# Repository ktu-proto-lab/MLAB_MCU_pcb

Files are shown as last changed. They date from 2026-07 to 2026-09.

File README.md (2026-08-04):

# MLAB_MCU Test PCB

Test board for the taped-out `MLAB_MCU` (top level: `ibex_simple_system`), packaged in a
QFN32 / MLP5X5-32 open-cavity package.

Socket: https://lt.farnell.com/3m/232-5205-01/test-socket-qfn-32pos-0-5mm-th/dp/2668401?cfm=true

Two board versions, one schematic project:

| Version | Purpose | Notes |
|---|---|---|
| **A - Socketed (Priority)** | Screening / characterisation of multiple dies | Full instrumentation.  |
| **B - Direct solder (Future)** | Demo, long-term lab setup | Same schematic, instrumentation depopulated (fixed LDOs, fixed oscillator). |

---

## 1. Chip summary

- Ibex RV32IMC core, Wishbone shared interconnect
- IMEM 8 kB, DMEM 4 kB
- Peripherals: I2C master, UART master, GPIO(10), timer
- Bootloader loads firmware from an external I2C EEPROM (24CS512), writes back SRAM contents to another region of the EEPROM, then releases `rst_core`
- Full scan chain, enabled by `test_mode` (**active high**)
- Timing closed at **80 MHz** (`clk_sys`)

### Top-level chip ports

```
VDD, VSS, VDDPAD, VSSPAD       // 1.2 V core, 3.3 V pad ring
clk_sys_Pad                    // input
rst_sys_n_Pad                  // input, active low
SDA_Pad, SCL_Pad               // inout
ext_pad[9:0]                   // inout
test_mode_Pad                  // input, active high
```

### Pin function map

| Pin | `test_mode = 0` | `test_mode = 1` |
|---|---|---|
| `ext_pad[0]` | GPIO0/UART_RX | - |
| `ext_pad[1]` | GPIO1/UART_TX | - |
| `ext_pad[2]` | GPIO2 | **scan_in (sdi)** |
| `ext_pad[3]` | GPIO3 | **scan_out (sdo)** |
| `ext_pad[4]` | GPIO4 | **scan_en** |
| `ext_pad[5..9]` | GPIO5..9 | - |
| `clk_sys_Pad` | system clock | scan shift clock |
| `rst_sys_n_Pad` | system reset | scan reset |

### Packaging / grounds

- Package base contact = **GND**. All unused package pins are bonded to the base.
- `VSSCORE` and `VSSPAD` are connected over this same base contact - **a single ground on the PCB**.

---

## 2. Power

Two rails, common ground.

| Rail | Nominal | Target accuracy at the pin |
|---|---|---|
| `VDD` (core) | 1.2 V | ±2 % from the regulator, ±5 % worst case at the pin |
| `VDDPAD` (I/O) | 3.3 V | ±2 % / ±5 % |

Rationale: timing libraries are characterised at ±10 %, and the worst IR drop seen in power
analysis was 20 mV. 

**Requirements**

- Two LDOs generating 1.2V and 3.3V with input connected to the same external 5V. Both rails brought through a jumper so that it can be disconnected and a bench SMU can replace the on-board LDO (for bringup and later a VDD-vs-Fmax test). 
- **Current sense:** high-side shunt + *INA4180 on each rail* - for amplified current sensing (don't know if necesary), SMA on the output to see high frequency 
Also bypass for bringup. Option for low-side shunt.
- **Decoupling**: 100 nF per supply pin, placed at the package. 1–10 µF bulk per rail.

---

## 3. Clock

`clk_sys` closed timing at 80 MHz, so the clock net is the fastest thing on the board.

**Requirements**

- Clock brought out to a SMA connector for external generator (for bringup and precise sweeps). 50 Ω shunt to ground at the connector. Some protection in case wrong amplitude from the generator? TODO: ask RF people!
- Fixed CMOS oscillator at 20MHz (regular operation, for SCL=100kHz).
- Header for FPGA (slow scan shifting clock).
- 3-pos jumper to choose between the CMOS oscillator and external source through SMA + 2-pos jumer for clk from FPGA.

---

## 4. Reset

`rst_sys_n_Pad` is a **wired-OR**: any source asserting low wins, a single pull-up is the only high source.

- **10 kΩ pull-up to VDDPAD** on `rst_sys_n_Pad`.
- **SPDT slide switch** as the manual bring-up reset: one throw ties the pole to GND, the other to VDD. 
- **FPGA pin, configured open-drain**, for software-controlled reset.
- Debounce capacitor on the net.
- Pads have Schmitt-trigger inputs, so no external buffer is needed on the RC edge.

---

## 5. test_mode and scan

`test_mode` is **active high**.

- 10 kΩ pull-**down** on `test_mode_Pad`, plus a header so that FPGA could force it high.
- Scan pins `ext_pad[2]` (sdi), `ext_pad[3]` (sdo), `ext_pad[4]` (scan_en) should stay electrically clean when scan is used - no LED, no pull-up/down.

- Note: scan shifting uses clk_sys, so the external clock path must pass DC-to-80 MHz.

---

## 6. Boot EEPROM and I2C

- **Socket** for the 24CS512 (DIP-8 socket so firmware images can be swapped by swapping the EEPROM).
- **Header** in parallel with the EEPROM for FPGA emulation of the I2C slave. **If the header is used, the EEPROM is removed.** No isolation logic.
- Pull-ups: **4.7 kΩ** on SDA and SCL. At 80MHz `clk_sys` SCL will be 400kHz, for that add another set of **4.7 kΩ** as DNP in parallel.
- `A0..A2` and `WP`all tied to GND as in earlier testing.
- Test points on SDA and SCL. Plus ground probe loop.
- **Sensor header:** a 4-pin (3V3 / GND / SDA / SCL) header on the same bus so an I2C sensor breakout can be plugged in for peripheral testing. Nothing populated by default.

---

## 7. GPIO and UART

- Series resistor 33 Ω on every `ext_pad` to limit max current (IO pad can source 16mA).
- LEDs+1kΩ resistor, each with a disconnectable jumper.
- Test point on every `ext_pad`. (Reuse the header)
- UART: no on-PCB bridge - use an external one from the header.

---

## 8. FPGA / host interface

- If we use the PYNQ-Z2 3.3 V logic on both sides, so no level shifting needed.
- One header carrying: `clk_sys`, `rst_sys_n`, `test_mode`, all 10 `ext_pad`, SDA, SCL, 3V3, GND.

---

## 9. PCB and mechanical

- 4-layer, with solid ground plane on L2 ??
- Package base pad = GND, make sure to add contact for it
- **Silkscreen the pin function map (§1) on the board.**

---

## 10. Bring-up order

1. Bare board: check rails, no shorts. Chip not fitted.
2. Fit chip. Power up IO ring and have the supply limited to 30mA or something
2. Then power up the IO ring with the Core, supply current limited again
3. Reset still held.  Apply a slow clock and step it (1, 5, 10 MHz). Core current should rise roughly linearly with frequency, if not - clock isn't reaching the die. If jumps to something large - contention or latch-up.
4. T1 from §12. `test_mode = 1`: shift a known pattern through sdi -> sdo. This proves the die is alive and the pad ring works, before any firmware exists.
5. EEPROM fitted. Release reset, verify writeback works.(Can skip to GPIO example). Use 20MHz clock.
6. EEPROM fitted with a blink program. Release reset, watch a GPIO toggle.
7. UART hello-world.
8. Ramp clock to 80 MHz, then shmoo.

---

## 11. Test plan

### T1 - Scan chain integrity (structural)
Shift a known pattern (walking 1, PRBS) through sdi -> sdo at a slow clock, compare.
- **Answers:** is the die alive, is the pad ring alive, is the chain unbroken?
- **Needs:** test_mode header, clean ext_pad[4:2] to FPGA header, slow clock path.
- **Why first:** no firmware, no EEPROM. Cheapest go/no-go.
- **Future test:** re-run at increasing shift frequency to find scan-shift Fmax.

### T2 - Static power
Measure VDD and VDDPAD current with reset held and clock stopped, sweeping VDD.
- **Answers:** leakage vs supply; compares against the PnR power estimate.
- **Needs:** bench VDD.

### T3 - Dynamic power
At fixed VDD, sweep clock frequency and record core current. Repeat for a few VDD points.
- **Answers:** slope gives effective switched capacitance (I = C_eff · V · f), intercept
  gives leakage. Direct measured-vs-simulated comparison with the PnR power analysis.
- **Needs:** swept clock, INA226, a firmware workload with a stable
  activity factor (idle loop vs. busy loop gives two useful data points).

### T4 - Shmoo: Fmax vs VDD
For each (VDD, frequency) point: reset, boot, run a self-test, check pass/fail.
- **Answers:**  how much margin the 80 MHz signoff actually had.
- **Needs:** adjustable VDD, swept clock, software-controlled reset, a fast pass/fail signal (see below).
- **Pass/fail signal:** firmware runs a checksum over a known computation and toggles
  a GPIO at a distinct rate on pass; anything else is a fail. Must complete in ms, not
  seconds, or the sweep takes all day.

### T5 - Boot, memory, and writeback
The bootloader loads firmware from EEPROM into IMEM/DMEM, then reads the SRAMs back out
to a separate EEPROM region. Useful for debugging if the IC doesn't work. Can also perform thorough memory integrity testing.

### T6 - Peripherals
| Peripheral | Test |
|---|---|
| GPIO | Walking-1 out, read back via FPGA header; check drive strength / rise time |
| Timer | Compare programmed interval against scope / FPGA counter; measure drift |
| UART | Sweep baud rate, find max reliable rate; check baud error at 115200 |
| I2C master | Talk to a sensor on the header; sweep SCL frequency, check timing conformance |

### T7 - Die-to-die variation
Repeat T1–T4 across all packaged parts using the socketed board.
- **Answers:** yield, spread of Fmax and leakage across dies.
- **Needs:** the socket, and the whole loop scripted end-to-end.

### T9 - Robustness
- Reset behaviour: glitch reset, brown-out VDD, check recovery.
TBD further

### T10 - Benchmark
CoreMark at max stable frequency.

### T11 - Scan-chain testing with automatically generated test patterns
Use ATPG test patterns for a high coverage scan-chain test

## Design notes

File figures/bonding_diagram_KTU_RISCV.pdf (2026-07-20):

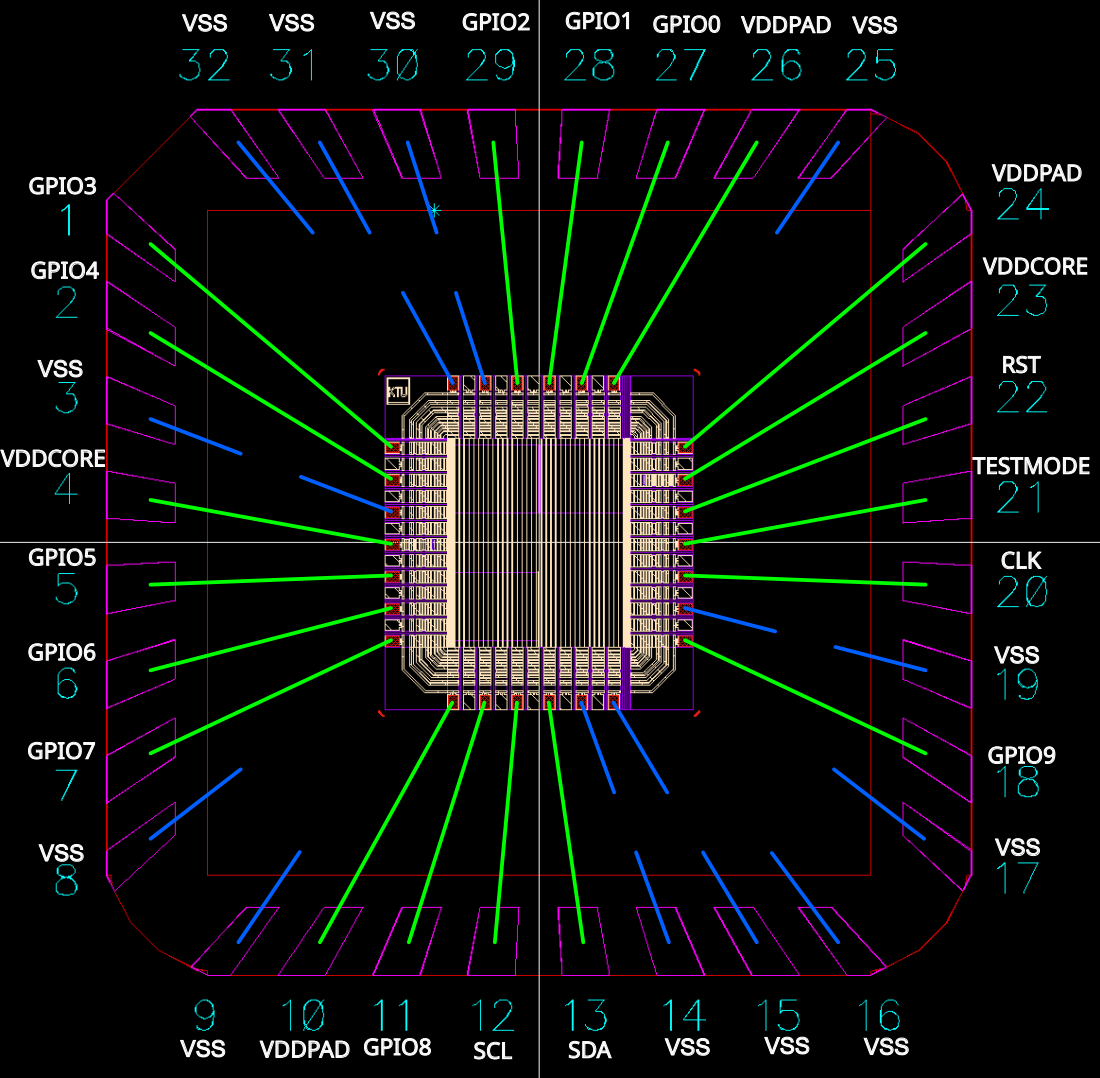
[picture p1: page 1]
RST; TESTMODE; GPIO9; GPIO8; GPIO3; GPIO4; VDDCORE; VDDPAD; GPIO2 GPIO1 GPIO0; VSS; VDDPAD VSS; GPIO5; GPIO6; GPIO7; SCL; SDA; CLK

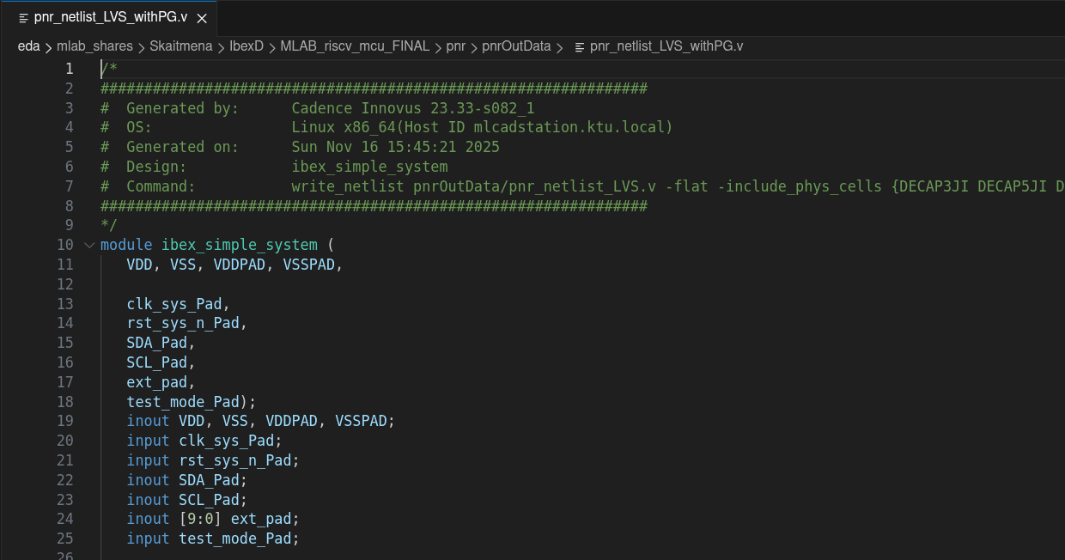
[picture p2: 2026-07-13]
figures/post_pnr_module_ports.png

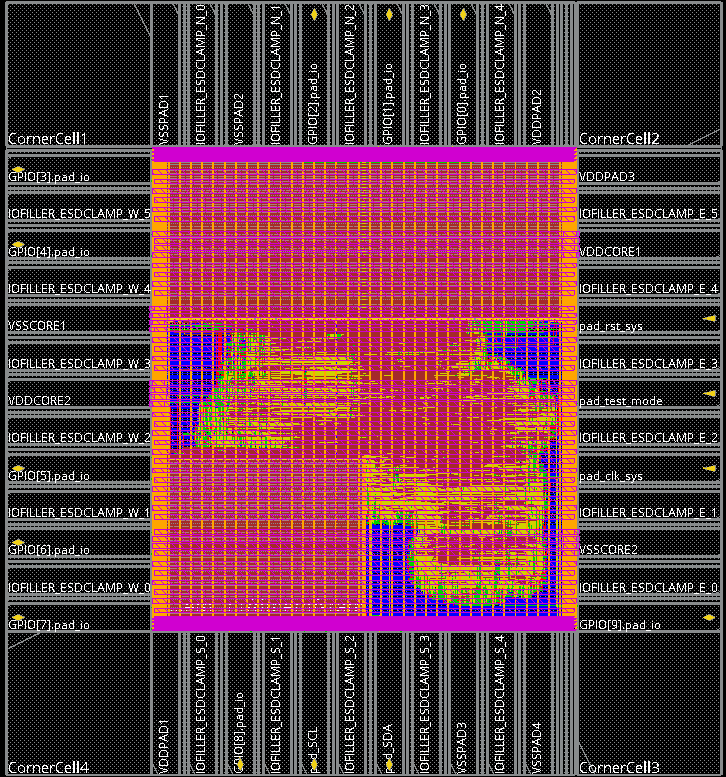
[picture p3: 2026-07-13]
figures/innovus_view.png

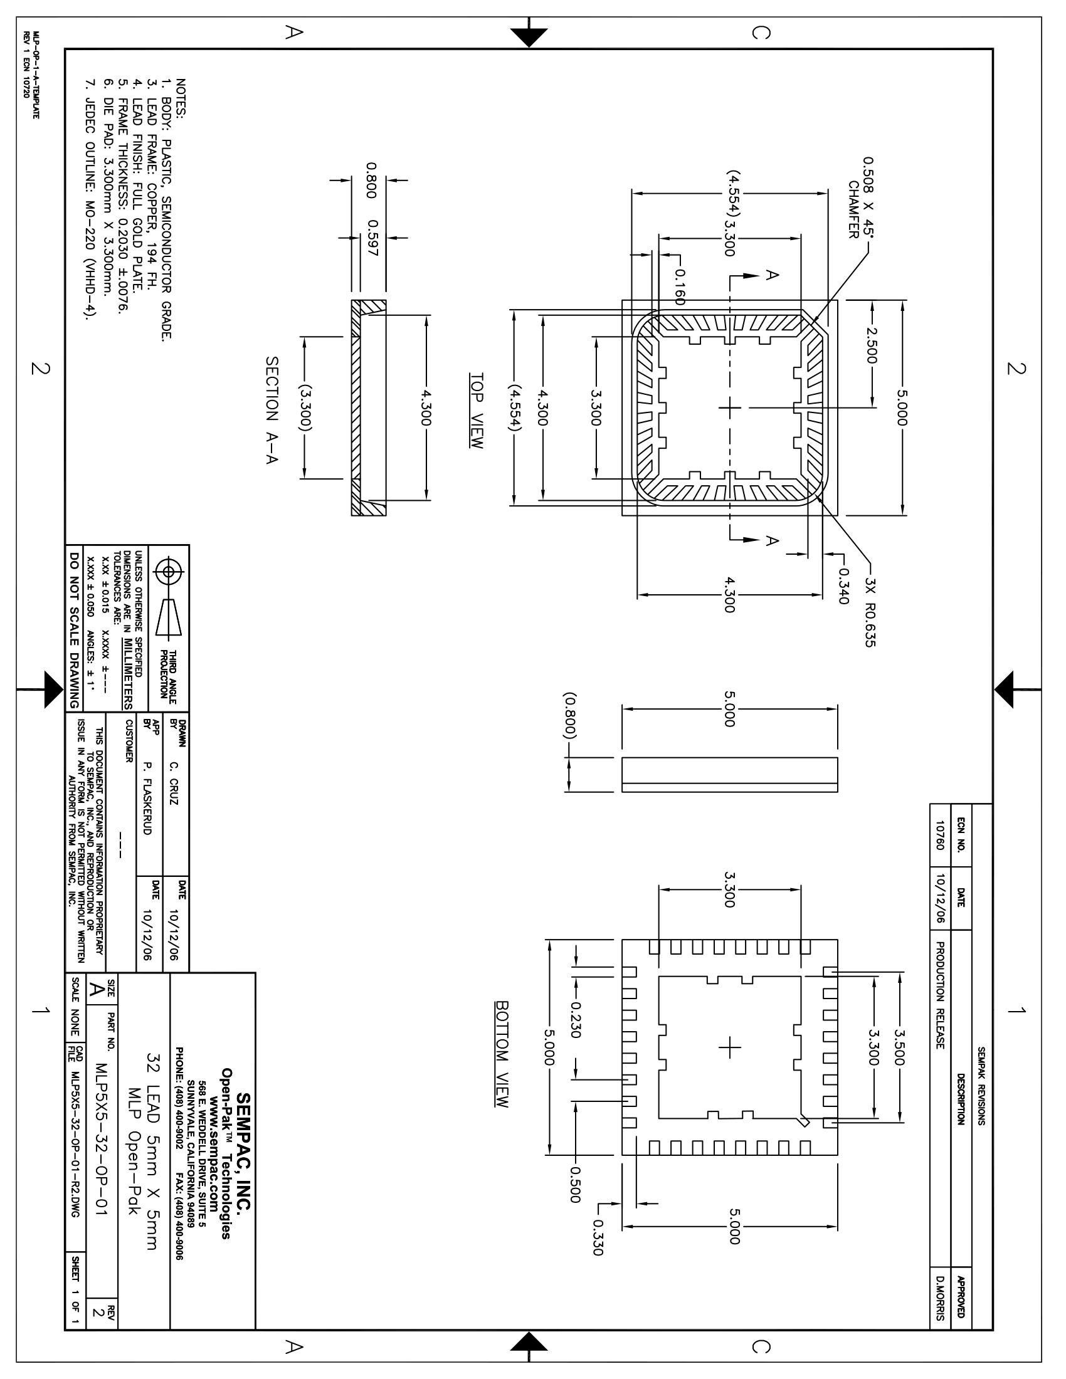
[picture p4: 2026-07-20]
figures/MLP5X5-32-OP-01-R2-ECN-10760-1.png

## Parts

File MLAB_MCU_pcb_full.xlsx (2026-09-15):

Reference | Qty | MP | Value | Footprint | Datasheet
C18 | 2 | 860240473003 | 47u | Capacitor_THT:CP_Radial_D5.0mm_P2.00mm
J11,J12 | 3 | 10129382-912003BLF | Conn_02x06_Odd_Even | Connector_PinHeader_2.54mm:PinHeader_2x06_P2.54mm_Horizontal
U4 | 2 | 24LC512-I/P | 24LC512 | Package_DIP:DIP-8_W7.62mm_Socket | http://ww1.microchip.com/downloads/en/DeviceDoc/21754M.pdf
R11,R12,R13,R14,R15,R16,R17,R18,R19,R20 | 10 | AC0805FR-0733RL | 33 | Resistor_SMD:R_0805_2012Metric_Pad1.20x1.40mm_HandSolder
R3 | 2 | AC0805JR-0756RL | 56 | Resistor_SMD:R_0805_2012Metric_Pad1.20x1.40mm_HandSolder
C1,C2,C4,C5,C8,C12,C13 | 10 | CC0805KKX7R8BB105 | 1u | Capacitor_SMD:C_0805_2012Metric_Pad1.18x1.45mm_HandSolder
C3,C6,C7,C9,C11,C14 | 10 | CC0805KRX7R9BB104 | 0.1u | Capacitor_SMD:C_0805_2012Metric_Pad1.18x1.45mm_HandSolder
U1 | 2 | DSC1101DL5-020.0000 | DSC1101DL5-020.0000 | 1_mlab_mcu_fp:VDFN6_2P5X2_MCH | DSC1101DL5-020.0000
U5 | 2 | INA4180A1IPWR | INA4180A1 | Package_SO:TSSOP-14_4.4x5mm_P0.65mm | https://www.ti.com/lit/ds/symlink/ina4180.pdf
D1,D2,D3,D4,D5,D6,D7,D8,D9,D10 | 10 | LTST-C171GKT | LED | LED_SMD:LED_0805_2012Metric_Pad1.15x1.40mm_HandSolder
R22,R23,R24,R25,R26,R27,R28,R29,R30,R31 | 10 | RC0805FR-071KL | 1k | Resistor_SMD:R_0805_2012Metric_Pad1.20x1.40mm_HandSolder
R7,R21,R32 | 5 | RC0805FR-071RL | 1 | Resistor_SMD:R_0805_2012Metric_Pad1.20x1.40mm_HandSolder
R4,R6 | 5 | RC0805FR-074K7L | 4.7k | Resistor_SMD:R_0805_2012Metric_Pad1.20x1.40mm_HandSolder
R1,R10 | 10 | RC0805FR-0710KL | 10k | Resistor_SMD:R_0805_2012Metric_Pad1.20x1.40mm_HandSolder
R9,R33,R34 | 3 | RC0805FR-07100RL | 100 | Resistor_SMD:R_0805_2012Metric_Pad1.20x1.40mm_HandSolder
J3,J9,J23,J24 | 4 | SMA-J-P-H-ST-TH1 | Conn_Coaxial | Connector_Coaxial:SMA_Amphenol_132134_Vertical
D12 | 2 | SMAJ6.0A | SMAJ6.0A | Diode_SMD:D_SMA | https://www.littelfuse.com/media?itemid=75e32973-b177-4ee3-a0ff-cedaf1abdb93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
D11 | 2 | SS34 | SS34 | Diode_SMD:D_SMA | https://www.vishay.com/docs/88751/ss32.pdf
S1 | 2 | SWS065-030V12TSK | SWS065-030V12TSK_REVA | 1_mlab_mcu_fp:SW_SWS065-030V12TSK_REVA
J1 | 1 | TBC05-02-1-G-G | TBC05-02-1-G-G | TerminalBlock_Phoenix:TerminalBlock_Phoenix_MPT-0,5-2-2.54_1x02_P2.54mm_Horizontal
U3 | 2 | TLV70233DBVR | TPS7A2033PDBVR | Package_TO_SOT_SMD:SOT-23-5 | https://www.ti.com/lit/gpn/tlv702
U2 | 2 | TPS7A2012PDBVRG4 | TPS7A2012PDBVRG4 | Package_TO_SOT_SMD:SOT-23-5 | https://www.ti.com/lit/ds/symlink/tps7a20.pdf
 | 1 | INA4180A2IPWR | Current sense 50V/V
 | 2 | 61304011121 | 1x40 headers
 | 2 | 10129381-940001BLF | 2x20 headers
 | 4 | HEX-SPACER-M3X12 | 12mm hex spacer
 | 4 | 50M030050P006 | 6mm M3 screw

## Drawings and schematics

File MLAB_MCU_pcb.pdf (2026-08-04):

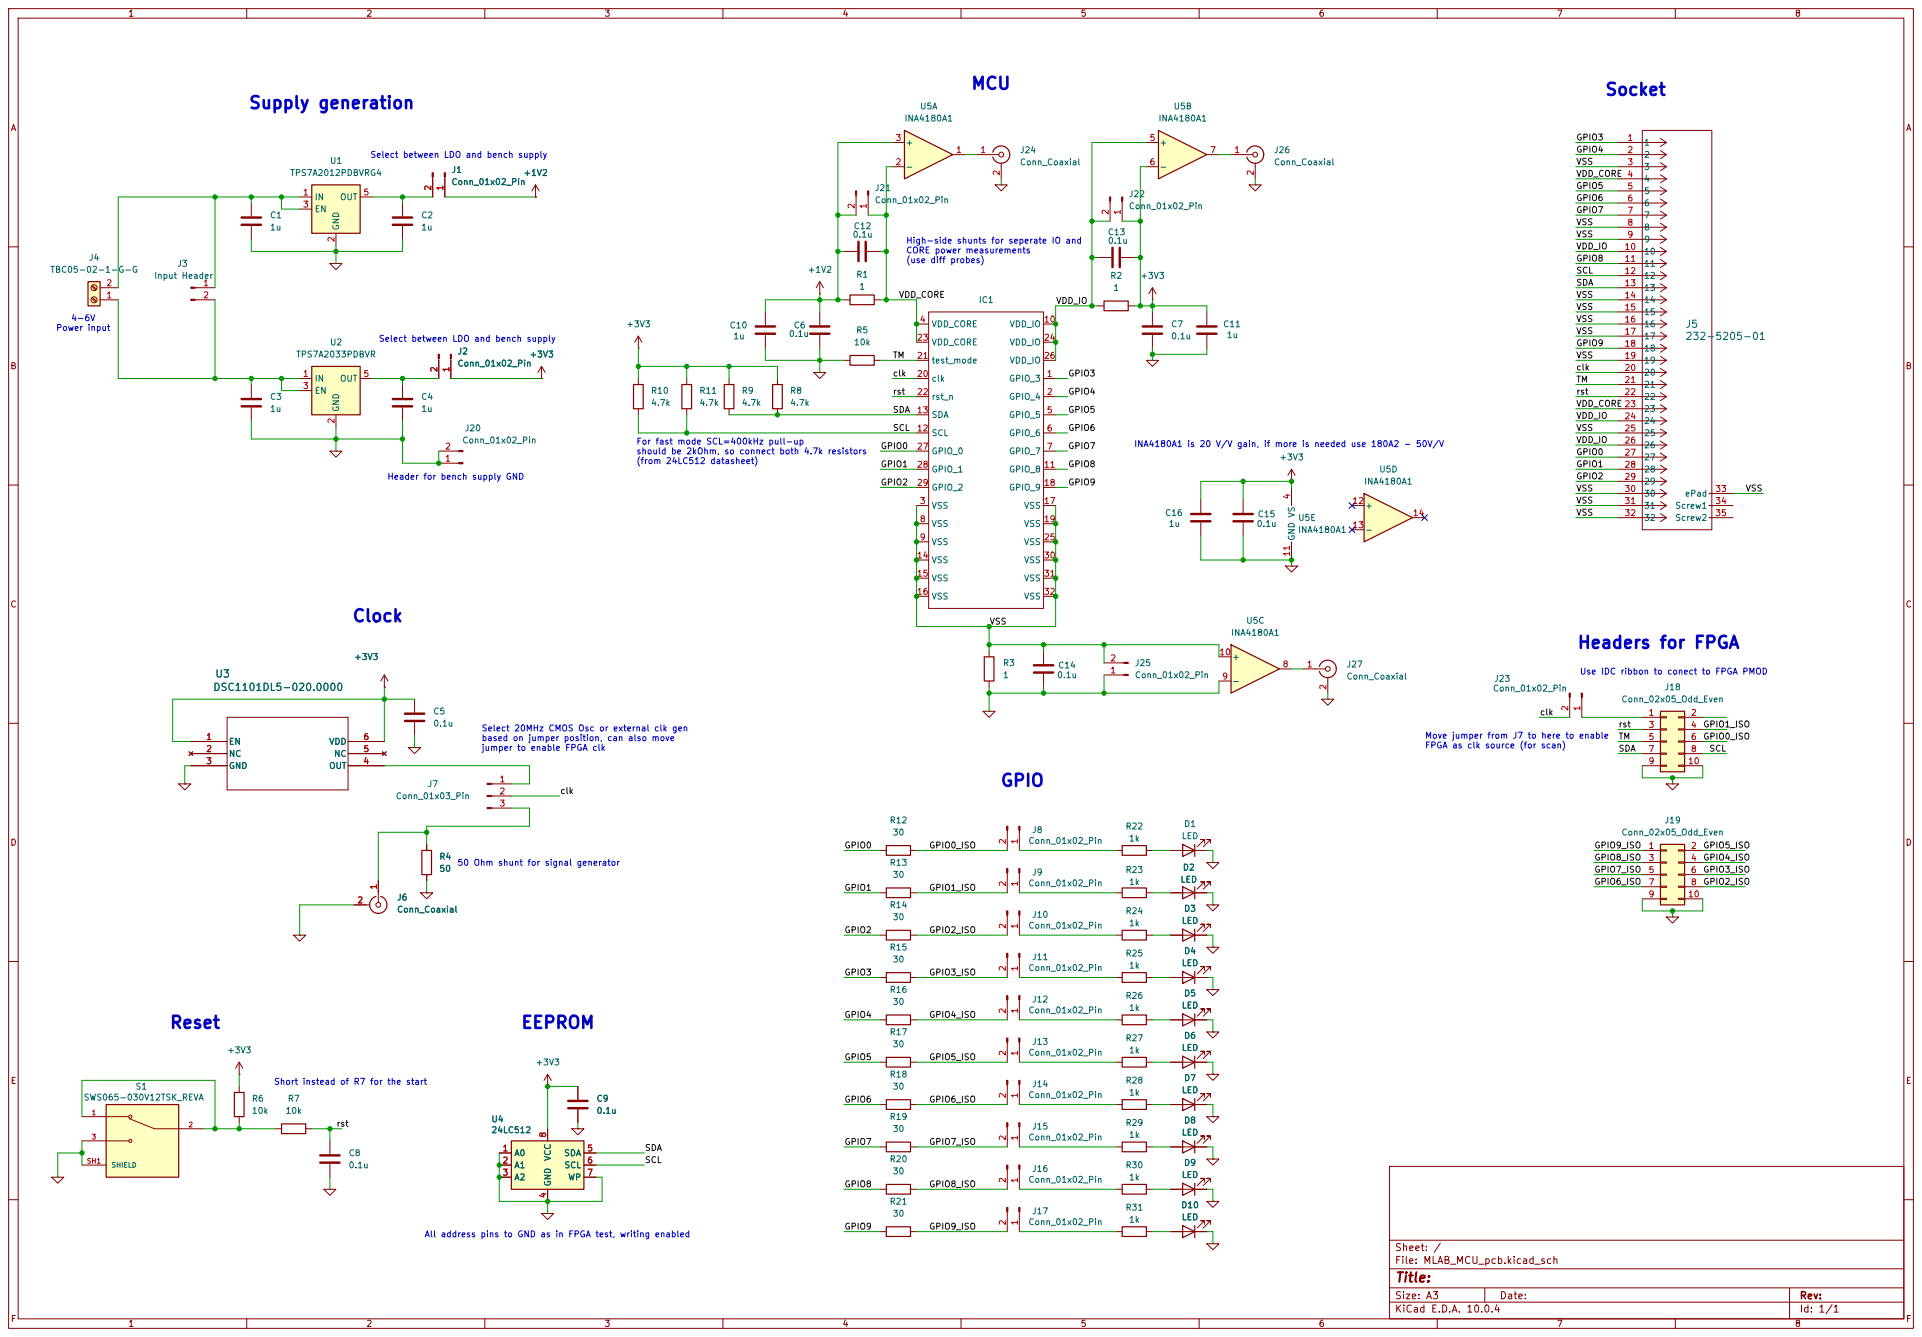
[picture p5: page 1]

Select between LDO and bench supply

High-side shunts for seperate IO and CORE power measurements

(use diff probes) Select between LDO and bench supply 50 Ohm shunt for signal generator Select 20MHz CMOS Osc or external clk gen based on jumper position, can also move

For fast mode SCL=400kHz pull-up should be 2kOhm, so connect both 4.7k resistors

INA4180A1 is 20 V/V gain, if more is needed use 180A2 - 50V/V

Header for bench supply GND Reset

jumper to enable FPGA clk +3V3

Use IDC ribbon to conect to FPGA PMOD
J18 Conn_02x05_Odd_Even 2

Short instead of R7 for the start

Size: A3 | Rev:
KiCad E.D.A. 10.0.4 | Id: 1/1 | F Date:

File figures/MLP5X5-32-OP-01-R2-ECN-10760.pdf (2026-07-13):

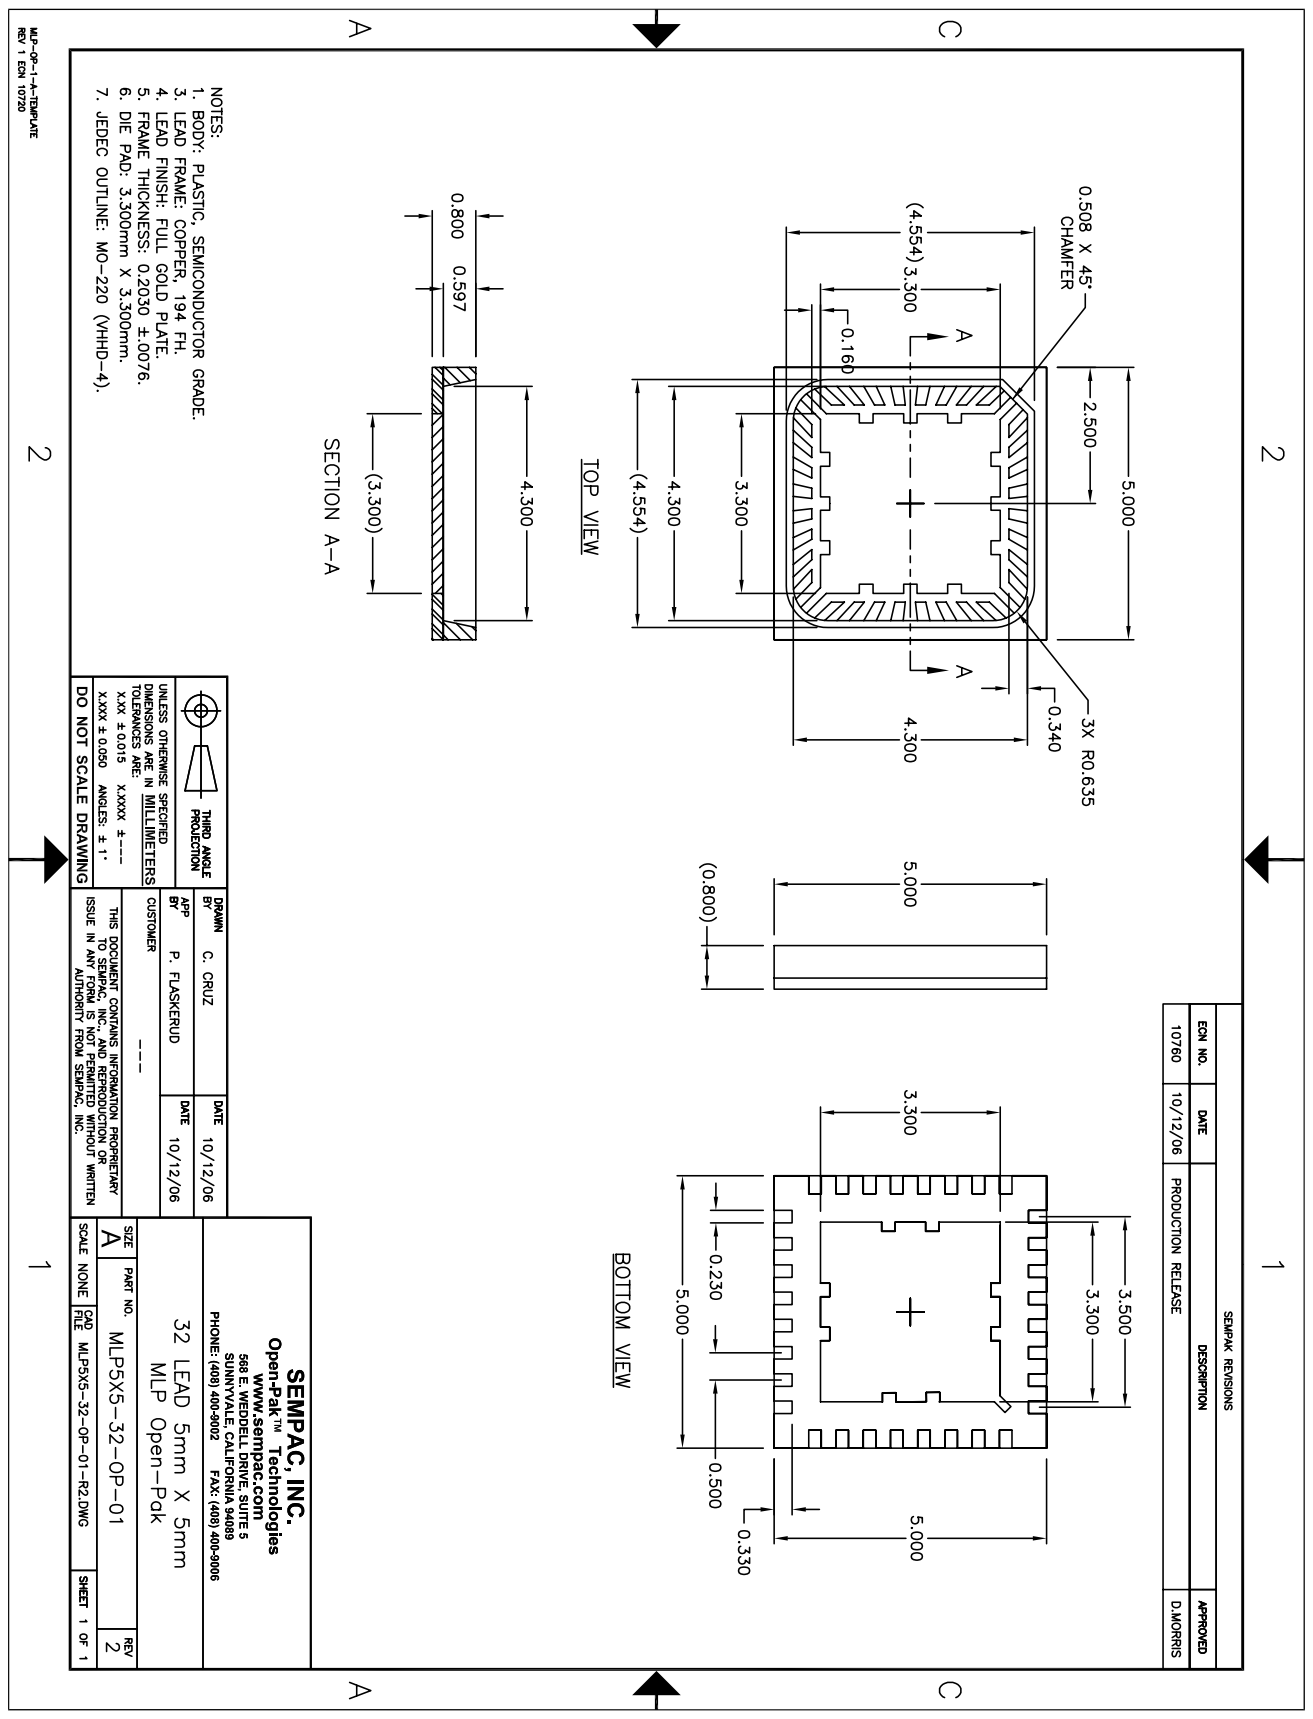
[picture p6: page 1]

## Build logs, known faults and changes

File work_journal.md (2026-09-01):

# Work journal for the MLAB_MCU test PCB

## TODO

- Add links for each component for automatic BOM generation

## 2026-07-19

- Create schematic + footprint for the ordered socket
- Start working on the schematic

Found socket for IC. TODO: Verify the test IC pin ordering when we receive the physical socket.

Chose TPS7A2012 and TPS7A2033 LDOs. Will put LDOs in parallel not efficient but for a bringup board it is fine. More simple design easier to customize for testing.

Chose DSC1101DL5-020.0000 20MHz oscillator - cheapest in mouser and good availability. Can be supplied from 3.3V.

Put a header and a screw terminal for input power to LDOs.

# 2026-07-28
CMOS Clock oscillator:
https://eu.mouser.com/en/ProductDetail/Microchip-Technology/DSC1101DL5-020.0000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

# 2026-08-02
## TODO
- Add switch for rst
- Add EEPROM socket (DIP-8)

# 2026-08-03
## Ernesto pastebejimai
1. Gnd kontaktu maitinimo saltiniui is lab bench
2. sroves stiprintuvas suntams
3. Clock apdaryt 3 pos header kad pasirinkt tarp sma ir CMOS osc ir dar papildoma 2pos kad prijungti fpga
4. perkelti gpio jungima i fpga kad butu uz nuoseklio varzos
5. 

# 2026-09-01
- Mounting holes on the corners to lift pcb from the ground (minor protection against backside shorts)
- Remake FPGA PMODs to connect directly to FPGA without intermediate wires, add testpoints next to PMOD.

- Custom DRC rules from - https://github.com/Cimos/kicad-druid/blob/main/JLCPCB/JLCPCB.kicad_dru
- Add MF part numbers for BOM generation to key components

# BOM
- Socket: https://lt.farnell.com/3m/232-5205-01/test-socket-qfn-32pos-0-5mm-th/dp/2668401?cfm=true
- CMOS Clock oscillator:
https://eu.mouser.com/en/ProductDetail/Microchip-Technology/DSC1101DL5-020.0000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
- LDO 3V3: https://www.mouser.lt/en/ProductDetail/Texas-Instruments/TPS7A2033PDBVR?qs=hd1VzrDQEGjk%2FOBnRfKB4A%3D%3D
- LDO 1V2: https://www.mouser.lt/en/ProductDetail/Texas-Instruments/TPS7A2012PDBVRG4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
- EEPROM: https://www.mouser.lt/en/ProductDetail/Microchip-Technology/24LC512-I-P?qs=JmwSjbzn2OL8zYUOM6epRw%3D%3D
- Current-sense amp (4 channel):
    - 20 V/V: https://www.mouser.lt/en/ProductDetail/Texas-Instruments/INA4180A1IPWR?qs=f9yNj16SXrIc8%252Bkjpx1s2w%3D%3D
    - 50 V/V: https://www.mouser.lt/en/ProductDetail/Texas-Instruments/INA4180A2IPWR?qs=chTDxNqvsykNfIKY08v%252BVA%3D%3D
    - 100 V/V: https://www.mouser.lt/en/ProductDetail/Texas-Instruments/INA4180A3IPWR?qs=chTDxNqvsynaXF8xKMZ2OQ%3D%3D
    - SS34
    - SMAJ6.0A
    -

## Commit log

2026-07-13 Initial PCB spec
2026-07-14 simplify the pcb spec"
2026-07-14 Improve pcb spec from Ole's comments"
2026-07-20 Collecting components and starting work on schematic
    [MLAB_MCU_pcb.kicad_sch]
2026-08-02 Schematic WIP
    [MLAB_MCU_pcb.kicad_sch]
2026-08-03 Schematic still WIP
    [MLAB_MCU_pcb.kicad_sch]
2026-08-03 Schematic done
    [MLAB_MCU_pcb.kicad_sch]
2026-08-04 Add Current-sense amps for all shunts
    [MLAB_MCU_pcb.kicad_sch]
2026-08-06 Initial PCB layout
    [MLAB_MCU_pcb.kicad_pcb, MLAB_MCU_pcb.kicad_sch]
2026-08-28 Adjust socket footprint, add text on silkscreen
    [MLAB_MCU_pcb.kicad_pcb]
2026-09-01 Redo FPGA PMOD for direct connection; Add mounting holes in the corners
    [MLAB_MCU_pcb.kicad_pcb, MLAB_MCU_pcb.kicad_sch]
2026-09-01 Add DRC for jlcpcb; minor layout changes
    [MLAB_MCU_pcb.kicad_pcb, MLAB_MCU_pcb.kicad_sch]
2026-09-01 Routing WIP
    [MLAB_MCU_pcb.kicad_pcb, MLAB_MCU_pcb.kicad_sch]
2026-09-01 minor changes
    [MLAB_MCU_pcb.kicad_pcb]
2026-09-07 Fix FPGA PMOD spacing
    [MLAB_MCU_pcb.kicad_pcb]
2026-09-10 Some PCB changes
    [MLAB_MCU_pcb.kicad_pcb]
2026-09-11 Minor layout fixes, DRC good
    [MLAB_MCU_pcb.kicad_pcb]
2026-09-15 Final changes and output files
    [MLAB_MCU_pcb.kicad_pcb, MLAB_MCU_pcb.kicad_sch, MLAB_MCU_pcb_full.xlsx]
2026-09-15 Sent for prod
    [MLAB_MCU_pcb.kicad_pcb]
